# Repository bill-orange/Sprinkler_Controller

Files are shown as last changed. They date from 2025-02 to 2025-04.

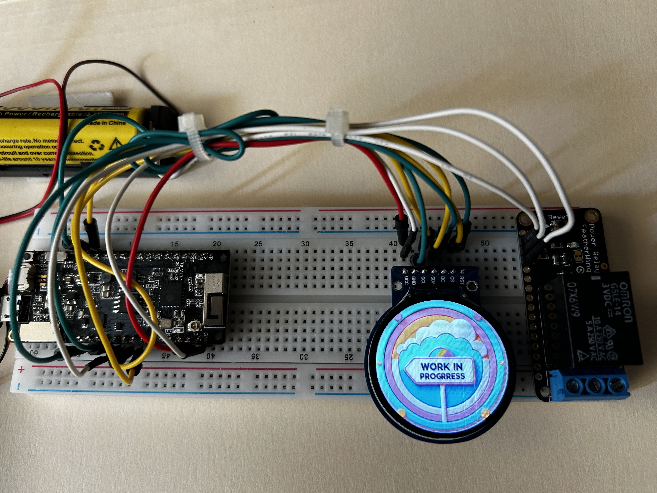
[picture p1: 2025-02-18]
IMG_1593.JPG

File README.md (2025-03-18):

I use an open source sprinkler controller to control the time and duration that my lawn is watered. 
The microcontroller code in the controller attempts to adjust the watering duration based on weather.
It is seldom accurate.  Frequently, I look outside to see drizzling rain and the sprinklers running.

This project is an attempt to save water by more accurately inhibiting watering.  A relay will 
open the ground line to the sprinklers when the project deems that watering is not appropriate.
It does this by obtaining the current weather conditions and the forecast from OpenWeatherMap.  If it 
is raining or expected to start raining shortly, watering will be inhibited.  Simple so far.

If it is not raining and not forecast to start raining in the very near future, watering may still be inappropriate.
The OpenWeatherMap data is sent to OpenAI which is asked for a "Yes" or "No" on inhibiting watering.
If "Yes" watering will run.

My hope is that this setup will be more accurate than the approach taken in the existing sprinkler controller.

The project uses a colorful TFT display and a 3v relay board.  Be sure to configure your TFT_eSPI library for your display.
There are lots of instructions on how to do this on YouTube. The microcontroller is a TTGO T8 v1.7.1.
By minor modifications to pin assignments, you should be able to use your choice of hardware.  Be sure to use a 3v relay board.
ESP32 Dev Boards are not 5v tolerant.  I have included a Fritzing file but it is unliky to work for your part choices.
You will need OpenAI and OpenWeatherMap API keys.  They are easily optained. OpenAI costs 
a small amount of money to run.  Please note, this is not a libray. Put the .c and .h files in the same folder 
as the project folder containing the .ino file.



There are a couple of interesting innovations in this project. All graphics are AI genereated PNG files.
They are not stored in the sketch.  They are downloaded from the GitHub page when needed.  You can have 
as many graphics as you like without using up limited microcontroller memory.  You can change them whenever
you like without recompiling.  The OpenAI prompt is also stored in the GitHub site instead of in the sketch.
This allows the prompt to be refined without recompiling.

This project could be adapted to other applications, like controlling outdoor lights or running pool heaters.
Use at your own risk.

03/18/2025 OTA version added

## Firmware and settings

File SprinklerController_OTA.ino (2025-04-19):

/* William E Webb (c) MIT LICENSE Sprinker Controller Inhibit using OpenWeatherMap and ChatGPT
   
   This project uses TFT_eSPI by Bodmer The original starting point for this library was the
   Adafruit_ILI9341 library in January 2015. MIT License
   
   This project uses weathercall by François Crins 2nd. MIT License/
   
   This project uses ChatGPTuino by programming-electronics-acadamy 
   GNU Lesser General Public License v2.1

02/12/2025 First release - runs and appears to work but without rain, 
           I can not test the flow control.  Support_functions.h has been modified.
02/17/2025 Added fileInfo to startup.  Added WiFi Multi.
02/18/2025 Added MIT License
02/19/2025 Added Graphic to show WiFi is connected.
02/22/2025 Added explaination of decision print to serial
           Can not print to SD because of pin duplication
02/25/2025 Improved download speed in support_functions.h revised
02/26/2025 Clarify rain/sun if statement
03/02/2025 Move DC pin from GPIO2 to GPIO19 to free up SD card I/O
           Added SD card support of storing AI messages. Untested!
03/03/2025 Added uSD Card loading graphics
           Added Generalized Graphics function
03/02/2025 Minors
03/02/2025 Minors
03/07/2025 Minors
03/12/2025 Added more conditions that will display error message
03/14/2025 Minors
03/17/2025 Moved explaination prompt into github Started OTA work
03/18/2025 OTA and posting of last message added. Compile with Minimal SPIFFS
03/22/2025 Turn off green LED and blink it on after AI explain,
           Minors
03/26/2025 Forked for addding soil resistance -- Mostly UNTESTED
04/03/2025 Impoved Web Page - Testing
04/04/2025 Change Scaling to float - Still Testing
04/05/2025 Simplified and corrected server.on & lengthened timeout in support_function.h
04/07/2025 Added confused AI png file, Added tempString to web report - UNTESTED
04/10/2025 fixed variable names and scope errors
04/12/2024 Made String storage area a bit larger and compiled with new JSON library
04/14/2025 Greatly increased timouts on HTTP incuding within weathercall library.
04/17/2025 Tokens increased and minors

*/
//#define USE_LINE_BUFFER     // Enable for faster rendering
#define debug true          // eliminates print statements
#include <WiFi.h>           // Needed for Version 3 Board Manager
#include <WiFiMulti.h>      // Needed for more than one possible SSDI
#include <TFT_eSPI.h>       // Hardware-specific library
#include "FS.h"             // For SD Card
#include "SD.h"             // For SD Card
TFT_eSPI tft = TFT_eSPI();  // For Display

#include <HTTPClient.h>         // Get Web Data
#include <WiFiClient.h>         // For OTA
#include <WebServer.h>          // For OTA
#include <ElegantOTA.h>         // OTA Library ESP32 compatable
#include "support_functions.h"  // Process PNG for TFT display
#include <weathercall.h>        // Get Open WeatherMap data
#include <ChatGPTuino.h>        // For AI Support
#include <CRC8.h>               // CRC8 library
#include <CRC.h>                // CRC library
#include "secrets.h"            //  Just what the name implies plus location info

SPIClass hspi(HSPI);  // Start SPI instance

SET_LOOP_TASK_STACK_SIZE(14 * 1024);  // needed to handle really long strings

#define DISPLAYBAUD 115200                         // set for LoRa communication/#define DISPLAYBAUD 115200
#define RELAY_PIN 5                                // Define the pin connected to the relay
#define LED_PIN 21                                 // only likely correct for T8 board
#define MYPORT_TX 22                               // Transmit pin for serial
#define MYPORT_RX 27                               // Receive pin for serial
#define ADDRESS 2                                  // Address of receiving LoRa.  Must be in same Network
#define TIME_Between_Weather_Calls (3600000 * 12)  // Every 12 Hours
//#define TIME_Between_Weather_Calls (3600000 * 1)  // Every 1 Hour -- For Testing Only!
//#define __FILENAME__ (strrchr(__FILE__, '\\') ? strrchr(__FILE__, '\\') + 1 : __FILE__)

String latitude = LAT;               // 90.0000 to -90.0000 negative for Southern hemisphere
String longitude = LON;              // 180.000 to -180.000 negative for West
String units = Units;                // or "imperial"
String language = Language;          // See notes tab
String jsonBuffer;                   // Storage for JSON String test, if needed
String tempString2 = " pending   ";  // The explaination of Yes/No reply
String tempString = " pending   ";   // The binary Yes/No reply
String incomingstring = "void";      // Unparsed LoRa message
String message = "unknown";          // Web message
String partialRealUserMessage;
String soilMessage = "200";             // Data from soil moisture transmitter
String signal_st = "void";              // Signal strenght in dB for some reason the word signal
                                        // is reserved in the ESP32 compiler
String sn = "00";                       // Signal-to-Noise Ratio
String lora_trans_prefix = "AT+SEND=";  // LoRa prefix send without CR/LF

char *AIShortReply = "                                                          ";  // AI Reply storage


// REASSIGN_PINS for uSD
int sck = 14;
int miso = 2;
int mosi = 15;
int cs = 13;

/*  For reference only do not uncomment - pin assigments for TFT Display
#define TFT_MISO 19
#define TFT_MOSI 23
#define TFT_SCLK 18
#define TFT_CS   12  // Chip select control pin
#define TFT_DC   19  // Data Command control pin
#define TFT_RST   4  // Reset pin (could connect to RST pin)
*/

const int TOKENS = 220;             // How lengthy a response you want, every token is about 3/4 a word
const int NUM_MESSAGES = 30;        // Another budget limit
const char *model = "gpt-4o-mini";  // OpenAI Model being used
//const char *model = "gpt-4o";     // OpenAI Model being used
const char *filename = "/AI_data.txt";

unsigned long previousMillis = 0;                           // Stores the last time the task was executed
unsigned long ota_progress_millis = 0;                      // OTA timer
const unsigned long interval = TIME_Between_Weather_Calls;  // 12-hour interval in milliseconds

int firstTime = 1;  // Run main program on startup or error

weatherData w;                                     // Instance of OpenWeatherMap retriever
Weathercall weather(apiKeyOpenWeather, location);  // Setup fetch
Weathercall forecast(apiKeyOpenWeather, location, 1);

ChatGPTuino chat{ TOKENS, NUM_MESSAGES };  // Will store and send your most recent messages (up to NUM_MESSAGES)
WiFiMulti wifiMulti;                       // Constructor for multiple wifi ssid
WebServer server(80);                      // OTA web server instance
CRC8 crc;                                  // Instance of CRC calculator


/*-------------------------------- Display Graphics ----------------------------------------*/
void showGraphic(String(image), int(relayState)) {
  uint32_t t = millis();

  setPngPosition(0, 0);
  String githubURL = GITHUBURL + image;
  const char *URLStr = githubURL.c_str();
  Serial.println(URLStr);
  load_png(URLStr);
  t = millis() - t;
  Serial.print(t);
  Serial.println(" ms to load URL");
  updateRelay(relayState);
}

/*-------------------------------- Setup ------------------------------------*/
void setup() {

  Serial.begin(115200);
  Serial2.begin(DISPLAYBAUD, SERIAL_8N1, MYPORT_RX, MYPORT_TX);
  delay(3000);
  Serial.println("Setup Running.......");
  Serial.print("compiler Version: ");
  Serial.println(__cplusplus);
  pinMode(RELAY_PIN, OUTPUT);
  pinMode(LED_PIN, OUTPUT);  // Blink LED on data received
  updateRelay(1);
  tft.begin();
  tft.fillScreen(0);
  tft.setRotation(2);
  fileInfo();
  connectToWifiNetwork();
  delay(3000);
  chat.init(chatGPT_APIKey, model);  // Initialize AI chat

  hspi.begin(sck, miso, mosi, cs);
  delay(2000);

  // Initialize SD card
  if (!SD.begin(cs, hspi)) {
    Serial.println("SD card initialization failed!");
    showGraphic("SD_No.png", 1);
  } else {
    Serial.println("SD card initialized.");
    showGraphic("SD_Yes.png", 1);
  }
  delay(3000);
  // Check if the file exists
  if (SD.exists(filename)) {
    Serial.println("File exists.");
  } else {
    Serial.println("File does not exist. Creating file...");
    // Create the file
    File file = SD.open(filename, FILE_WRITE);
    if (file) {
      Serial.println("File created.");
      file.close();
    } else {
      Serial.println("Failed to create file.");
    }
  }
  //showGraphic("WIP.png", 1);
  digitalWrite(TFT_BL, LOW);  // Green LED off
  showGraphic("wait_for_it.png", 1);
  configureServer();  // Setup the server route
  server.begin();     // Start the server

  ElegantOTA.begin(&server);  // Start ElegantOTA
  // ElegantOTA callbacks
  ElegantOTA.onStart(onOTAStart);
  ElegantOTA.onProgress(onOTAProgress);
  ElegantOTA.onEnd(onOTAEnd);

  server.begin();
  Serial.println("HTTP server started");

  String incomingstring_check = " ";  // Keep the incoming checksone string local

  sleepMode(0);  // Want the transmitting LoRA to be awake
  delay(2000);

  Serial2.println("AT+RESET");
  delay(2000);
  Serial2.println("AT");
  do {


    if (Serial2.available()) {
      incomingstring_check = Serial2.readString();
    }

  } while (incomingstring_check.indexOf("+OK") == -1);  // Confusing.. This is a double negative

  Serial.print("Test before startup: ");
  Serial.println(incomingstring_check);

  Serial.println("------------------------------------------------------------------------");
  Serial.println(" Setup Complete ................ Getting Data");
}

/*------------------------------------------- Loop -----------------------------------------------*/
void loop() {

  server.handleClient();
  ElegantOTA.loop();
  getSoilMoisture();

  if (firstTime == 1) {

    if (main() == 1) {  // Run main after TIME_Between_Weather_Calls and recycle on error
      showGraphic("error.png", 1);
      firstTime = 1;
      yield();
    } else {
      firstTime = 0;
    }
  }

  // Check if 12 hours have passed
  unsigned long currentMillis = millis();
  if (currentMillis - previousMillis >= TIME_Between_Weather_Calls) {
    previousMillis = currentMillis;

    WiFi.disconnect();  // Re-establish network connection, just to be shure
    delay(2000);
    connectToWifiNetwork();
    delay(2000);

    //ESP.restart();      // Restart the ESP32

    if (main() == 1) {  // Run main after TIME_Between_Weather_Calls and recycle on error
      showGraphic("error.png", 1);
      firstTime = 1;
      yield();
    }
  }
  yield();  // Get ready for OTA call
}

/* ----------------------------------- Main loop separated from Lopp for non-blocking -------------------------*/
int main() {
  int consultAINeeded = 1;    // yes
  int error = 0;              // Tracks errors between functions
  weather.updateStatus(&w);   // Fetches weather
  forecast.updateStatus(&w);  // Fetches forecast

  if (strstr(w.weather.c_str(), "ain") != NULL || strstr(w.weather1.c_str(), "ain") != NULL || strstr(w.weather2.c_str(), "ain") != NULL) {
    consultAINeeded = 0;
    Serial.println("RAIN ............ RAIN ............... RAIN  >>>> No forecast needed");
    delay(3000);  // don't want to make server calls too close together
    showGraphic("12.png", 0);
  }
  if (consultAINeeded == 1) {
    yield();
    showGraphic("AI_computer_eye.png", 1);
    tempString = AIForecast();
    Serial.println("*****************************");
    Serial.println(tempString);
    Serial.println("*****************************");

    if (tempString.indexOf("NO") != -1) {
      showGraphic("11.png", 1);
    } else if (tempString.indexOf("YES") != -1) {
      showGraphic("12.png", 0);
    } else {
      showGraphic("confused_AI.png", 1);
    }

    if (debug && consultAINeeded == 1) {
      tempString2 = AIExplain();
      //configureServer();

      Serial.println(tempString2);
      const char *cstr = tempString2.c_str();
      appendFile(SD, filename, cstr);
      appendFile(SD, filename, "\n\n");
    }
    if (debug && consultAINeeded == 0) {
      appendFile(SD, filename, "rain ... rain ... rain \n\n");
    }
  }
  if (w.current_Temp == 0 || w.current_Temp1 == 0) {
    error = 1;
  }
  configureServer();
  yield();
  return error;
}

/*-------------------------------- Connect to the Wifi network ------------------------------------*/
void connectToWifiNetwork() {  // Boilerplate from example (mostly)

  delay(10);
  WiFi.mode(WIFI_STA);
  wifiMulti.addAP(ssid_1, password_1);
  wifiMulti.addAP(ssid_2, password_2);

  // WiFi.scanNetworks will return the number of networks found
  int n = WiFi.scanNetworks();
  Serial.println("scan done");
  if (n == 0) {
    Serial.println("no networks found");
    showGraphic("error.png", 1);
  } else {
    Serial.print(n);
    Serial.println(" networks found");
    for (int i = 0; i < n; ++i) {
      // Print SSID and RSSI for each network found
      Serial.print(i + 1);
      Serial.print(": ");
      Serial.print(WiFi.SSID(i));
      Serial.print(" (");
      Serial.print(WiFi.RSSI(i));
      Serial.print(")");
      Serial.println((WiFi.encryptionType(i) == WIFI_AUTH_OPEN) ? " " : "*");
      delay(10);
    }
  }

  // Connect to Wi-Fi using wifiMulti (connects to the SSID with strongest connection)
  Serial.println("Connecting Wifi...");
  if (wifiMulti.run() == WL_CONNECTED) {
    Serial.println("");
    Serial.println("WiFi connected");
    Serial.println("IP address: ");
    Serial.println(WiFi.localIP());
    WiFi.setAutoReconnect(true);  // Reconnect if disconnected
    WiFi.persistent(true);        // Reconnect if disconnected
    showGraphic("WiFiConnected.png", 1);
  } else {  // Handle error
    showGraphic("error.png", 1);
    delay(6000);
  }
}

/*-------------------------------- Gets Inhibit Criteria from Github -------------------------------------*/
String criteria() {  // Mostly from example
  uint32_t t = millis();
  HTTPClient http;
  http.setTimeout(120000);
  http.begin("https://raw.githubusercontent.com/bill-orange/Sprinkler_Controller/master/criteria.txt");

  int httpCode = http.GET();
  if (httpCode != HTTP_CODE_OK) {
    Serial.printf("HTTP ERROR: %d\n", httpCode);
    showGraphic("error.png", 1);
    http.end();
    return "   ";
  }

  String payload = http.getString();  // Read response into a String
  http.end();                         // Close connection

  t = millis() - t;
  Serial.print(t);
  Serial.println(" ms to load URL");
  yield();
  return payload;
}

/*-------------------------------- Gets Inhibit Explaination from Github -------------------------------------*/
String explain() {  // Written by AI
  uint32_t t = millis();
  HTTPClient http;
  http.begin("https://raw.githubusercontent.com/bill-orange/Sprinkler_Controller/master/explain.txt");

  int httpCode = http.GET();
  if (httpCode != HTTP_CODE_OK) {
    Serial.printf("HTTP ERROR: %d\n", httpCode);
    showGraphic("error.png", 1);
    http.end();
    return "   ";
  }

  String payload = http.getString();  // Read response into a String
  http.end();                         // Close connection

  t = millis() - t;
  Serial.print(t);
  Serial.println(" ms to load URL");
  yield();
  return payload;
}

/*----------------------------------- Send Prompt to AI ----------------------------------------*/
String AIForecast() {
  // Create the structures that hold the retrieved weather
  String realUserMessage = String(criteria())
                           + " Soil resistivity is: " + soilMessage + " Ohm-Meter\n"
                           + "Future forecast is provided in this JSON String\n"
                           + String(forecast.getResponse().c_str())
                           + " Current  weather is provided in this JSON String\n"
                           + String(weather.getResponse().c_str());  // User message to ChatGPT

  partialRealUserMessage = String(criteria())
                           + " Current weather is provided in this JSON String (redacted)\n"
                           + " Future forecast weather is provided in this JSON String (redacted)\n"
                           + " Soil resistance given to AI is: " + soilMessage + " Ohm-Meter.";


  // partialRealUserMessage = realUserMessage;

  Serial.println(realUserMessage);  // This and the lines below taken from library example
  int str_len = realUserMessage.length() + 1;
  char AIPrompt[str_len];
  realUserMessage.toCharArray(AIPrompt, str_len);
  GetAIReply(AIPrompt);
  //Serial.println(GetAIReply(AIPrompt));
  yield();
  return String(GetAIReply(AIPrompt));
}

/*----------------------------------- Process AI Call ----------------------------------------*/
char *GetAIReply(char *message) {  // Function taken from libary example
  chat.putMessage(message, strlen(message));
  chat.getResponse();
  return chat.getLastMessageContent();
}

/*----------------------------------- Relay Control ------------------------------------------*/
void updateRelay(int yesNo) {
  if (yesNo == 1) {
    digitalWrite(RELAY_PIN, HIGH);  // Close relay
  } else {
    digitalWrite(RELAY_PIN, LOW);  // Open relay
  }
}

/*----------------------------------- Send Explaination Prompt to AI ----------------------------------------*/
String AIExplain() {
  // Create the structures that hold the retrieved weather
  String realUserMessage = explain();

  Serial.println(realUserMessage);  // This and the lines below taken from library example
  int str_len = realUserMessage.length() + 1;
  char AIPrompt[str_len];
  realUserMessage.toCharArray(AIPrompt, str_len);
  GetAIReply(AIPrompt);
  digitalWrite(TFT_BL, HIGH);  // Green LED on, Bink to indicate explaination is ready
  delay(2000);
  digitalWrite(TFT_BL, LOW);  // Green LED off
  return String(GetAIReply(AIPrompt));
}

/*---------------------------- File information  ------------------------------------------*/
void fileInfo() {  // uesful to figure our what software is running


  tft.fillScreen(TFT_BLUE);
  tft.setTextColor(TFT_WHITE);  // Print to TFT display, White color
  tft.setTextSize(1);
  tft.drawString("    Sprinkler Inhibitor with OTA", 8, 60);
  tft.drawString("    AI Weather Prediction", 30, 70);
  tft.setTextSize(1);
  tft.drawString(__FILENAME__, 35, 1100);
  tft.drawString(__DATE__, 35, 140);
  tft.drawString(__TIME__, 125, 140);
  delay(3000);
}

/*---------------------------- Append File  ----------------------------------------*/
void appendFile(fs::FS &fs, const char *path, const char *message) {
  Serial.printf("Appending to file: %s\n", path);

  File file = fs.open(path, FILE_APPEND);
  if (!file) {
    Serial.println("Failed to open file for appending");
    return;
  }
  if (file.print(message)) {
    Serial.println("Message appended");
  } else {
    Serial.println("Append failed");
  }
  file.close();
}

/*---------------------------- Helper Functions for OTA----------------------------------------*/
void onOTAStart() {
  // Log when OTA has started
  Serial.println("OTA update started!");
  // <Add your own code here>
}

void onOTAProgress(size_t current, size_t final) {
  // Log every 1 second
  if (millis() - ota_progress_millis > 1000) {
    ota_progress_millis = millis();
    Serial.printf("OTA Progress Current: %u bytes, Final: %u bytes\n", current, final);
  }
}

void onOTAEnd(bool success) {
  // Log when OTA has finished
  if (success) {
    Serial.println("OTA update finished successfully!");
  } else {
    Serial.println("There was an error during OTA update!");
  }
  // <Add your own code here>
}

/*----------------------------Send message to web page----------------------------------------*/
void configureServer() {
  server.on("/", [&tempString2, &soilMessage, &tempString, &partialRealUserMessage]() {  // Capture by reference
    String message = "Hi! This is Sprinkler Controller. use /update for UPDATE \n\n Current Soil Resistance: "
                     + soilMessage
                     + " \n\n Latest Yes/No Decision: "
                     + tempString
                     + " \n\n Latest prompt: \n\n"
                     + partialRealUserMessage
                     + "\n\n Latest reply: \n\n"
                     + tempString2;

    server.send(200, "text/plain", message);
  });
  yield();
}

/*------------------------------- Parse Message ------------------------------------*/
void parseMessage() {

  // Very standard C++ parser for comma delimited String

  int first = incomingstring.indexOf(",");
  int second = incomingstring.indexOf(",", first + 1);
  int third = incomingstring.indexOf(",", second + 1);
  int fourth = incomingstring.indexOf(",", third + 1);
  int fifth = incomingstring.indexOf("\r", fourth + 1);

  soilMessage = incomingstring.substring(second + 1, third);
  signal_st = incomingstring.substring(third + 1, fourth);
  sn = incomingstring.substring(fourth + 1, fifth);
}

/*---------------------------------------------- CRC CAlculator ------------------------------------------------*/

uint8_t CRCCalculator(String message) {

  // CRC8 calculator see libraries examples on Github

  crc.reset();
  char char_array[message.length() + 1];
  message.toCharArray(char_array, message.length());
  crc.add((uint8_t *)char_array, message.length());
  return crc.calc();
}

/*---------------------------------------------- Data Transmitter ------------------------------------------------*/
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

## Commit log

2025-02-18 added PCB layout
    Untested and will only work with my component selection
    [SprinklerController.fzz]
2025-02-24 Update criteria.txt
    5mm to 2mm to count as significant rain,.
2025-03-02 Delete SprinklerController.fzz
    delete and replace with corrected TFT part
    [SprinklerController.fzz]
2025-03-02 Corrected TFT Part
    [Sprinkler_Controller_2-newpart.fzz]
2025-03-02 Update README.md
    show with PCB
2025-03-22 Turned off green LED and made it blink for explaination
    Tested Async web server and abandoned. It was incompatable with the uSD library and could caust WDT reboots even without it.
    [SprinklerController_OTA.ino]
2025-04-03 replace with new version
    [Sprinkler_Controller_2-newpart.fzz]
2025-04-03 latest layout
    [Sprinkler_Controller_8a_fill.fzz]
2025-04-07 add explicit critera for soil resistance.
2025-04-21 Update criteria.txt
    clarify soil resistance
2025-04-22 Update criteria.txt
    clarifies soil resistance.
